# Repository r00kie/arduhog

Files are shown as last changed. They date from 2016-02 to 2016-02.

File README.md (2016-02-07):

# Arduhog #

The aim of this project is to create pcb diagrams and software thanks to it will be possible to build hardware cockpit simulator for DCS A10C (and maybe more). PCB board and software try to simulate HID interface (keyboard exactly), so the knowledge that it is available here should also fit for other simulators/games. 

I'm lazy so im using Arduino Nano as main controller, it's cheap (if you are using chinese replacements), it's popular, you don't need any advanced hardware programmer and when you will be bored with this project you can use it for something else.

Project requires [this library](https://git.io/vgGM2) for working. You have to install it in your Arduino IDE.

You can also check [DCS-Bios](http://dcs-bios.a10c.de/), but it have a different approach, it's requires installing some additional scripts in DCS World and it's works only with A10C Cocpit. 

## Project Structure Description

### Hardware ###

  * eagle/ - directory containing EAGLE project; 
  * eagle/main_board - pcb diagrams for main board; mainly it contains all necessary components to simulate hardware keyboard and other stuff to indicate device status, some buttons (currently they do nothing); main board have 8 expansions port for extension board, it allows you to, theoretically, support up to 64 buttons/switches; connection to the PC is done via the USB B port (why B? because it is the simplest USB port for soldering and it fit to 100 mil boards)
  * eagle/ext_board - pcb diagrams for extension board; thanks to this board you can connect up to 16 button; 
  * eagle/ahcp - only schematic, how to connect switches from Armament Hud Control Panel to port what will fit extension board;
  * eagle/bom/* - Bill of Materials for pcb boards;
  * eagle/tests/* - tests and early material created for this project;

### Software ###

  * src/arduhog/* - source code for arduino controller;
  * src/arduhog/keymappings.ods - spreedsheet containing mapping from eagle/ahcp.sch to buttons in code and shortcuts in game.  

## Screenshots, images and movies  
  
  * [Image gallery of prototype](https://imgur.com/a/71ZCE)
  * [Working prototype](https://vid.me/YhLZ)

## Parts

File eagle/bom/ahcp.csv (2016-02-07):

Qty | Value | Device | Package | Parts | Description | A10
2 |  | PINHD-2X8 | 2X08 | JP1, JP2 | PIN HEADER
1 | MTS-103 | TL39PO | TL3XPO | S5 | TINY SWITCH ON OFF ON | Alt Sce
1 | MTS-103 | TL39PO | TL3XPO | S2 | TINY SWITCH ON OFF ON | GunPac
1 | MTS-103 | TL39PO | TL3XPO | S10 | TINY SWITCH ON OFF ON | IFFCC
1 | MTS-103 | TL39PO | TL3XPO | S3 | TINY SWITCH ON OFF ON | LASER Arm
1 | MTS-103 | TL39PO | TL3XPO | S1 | TINY SWITCH ON OFF ON | Master Arm
1 | MTS102 | TL36PO | TL3XPO | S8 | TINY SWITCH ON - ON | CICU
1 | MTS102 | TL36PO | TL3XPO | S6 | TINY SWITCH ON - ON | HUD Mode 1
1 | MTS102 | TL36PO | TL3XPO | S7 | TINY SWITCH ON - ON | HUD Mode 2
1 | MTS102 | TL36PO | TL3XPO | S9 | TINY SWITCH ON - ON | JTRS
1 | MTS102 | TL36PO | TL3XPO | S4 | TINY SWITCH ON - ON | TGP

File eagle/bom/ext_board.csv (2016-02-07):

Qty | Value | Device | Package | Parts | Description | TME_CODE
1 |  | LED3MM | LED3MM | LED1 | LED | L-934ID
2 |  | PINHD-2X8 | 2X08 | JP1, JP2 | PIN HEADER | 826632-8
1 | 100nF | C-EU050-030X075 | C050-030X075 | C2 | CAPACITOR, European symbol | CC-100N
19 | 10K | R-EU_0204/7 | 0204/7 | R1, R2, R3, R4, R5, R6, R7, R8, R9, R10, R11, R12, R13, R14, R15, R16, R18, R19, R20 | RESISTOR, European symbol | CF1/2WS-10K
1 | 10uF | CPOL-EUE2.5-7 | E2,5-7 | C3 | POLARIZED CAPACITOR, European symbol | UPW2A100MED
1 | 1N4001 | 1N4004 | DO41-10 | D1 | DIODE | 1N4001
1 | 270 | R-EU_0204/7 | 0204/7 | R21 | RESISTOR, European symbol | CF1/2WS-270R
1 | 33pF | C-EU050-030X075 | C050-030X075 | C1 | CAPACITOR, European symbol | FKP2-33P/1000-R
1 | 3K9 | R-EU_0204/7 | 0204/7 | R17 | RESISTOR, European symbol | 1/4W3.9K
1 | A6EX-310X | A6EX-310X | A6EX-310X | S1 | OMRON | A6E-3104
1 | MCP23016-I/SP | DIL28-3 | DIL28-3 | IC1 | Dual In Line | MCP23016-I/SP
1 | MX-171857-0004 | MX-171857-0004 | MX-171857-0004 | X1 |  | MX-7395-04B

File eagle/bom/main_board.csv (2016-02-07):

Qty | Value | Device | Package | Parts | Description | DX_CODE | MF | MPN | OC_FARNELL | OC_NEWARK | TME_CODE
1 | 100nF | C-EU050-030X075 | C050-030X075 | C2 | CAPACITOR, European symbol |  |  |  |  |  | CC-100N
1 | 10uF | CPOL-EUE2.5-7 | E2,5-7 | C3 | POLARIZED CAPACITOR, European symbol |  |  |  |  |  | UPW2A100MED
2 | 1K | R-EU_0204/7 | 0204/7 | R1, R2 | RESISTOR, European symbol |  |  |  |  |  | CF1/4W-1K
3 | 270 | R-EU_0204/7 | 0204/7 | R7, R8, R9 | RESISTOR, European symbol |  |  |  |  |  | CF1/2WS-270R
1 | 2K2 | R-EU_0204/7 | 0204/7 | R10 | RESISTOR, European symbol |  |  |  |  |  | 1/4W2.2K
2 | 3V6 | ZPD | DO35Z10 | D1, D2 | Z DIODE |  |  |  |  |  | ZPD3.6-DIO
2 | 68 | R-EU_0204/7 | 0204/7 | R11, R12 | RESISTOR, European symbol |  |  |  |  |  | CF1/2WS-68R
1 | Arduino Nano | DIL32 | DIL32 | IC1 | Dual In Line | 844081877 |  |  |  |  | N/A
2 | B3F-1000 | 10-XX | B3F-10XX | S1, S2 | OMRON SWITCH |  |  | B3F-1000 | 176432 | 36M3542 | B3F-1002
1 | GREEN | TLLR4400 | LED3MM | LED2 | Low Current (2mA) LED 3 mm Tinted Diffused Package color RED |  | VISHAY SEMICONDUCTOR |  | 1612437 |  | L-934GD
1 | MINI-USB_4P-85-32004-10X | MINI-USB_4P-85-32004-10X | 85-32004-10X | X9 | MINI USB 4 Pol. |  |  |  | unknown | unknown | USBB-G
8 | MX-171857-0004 | MX-171857-0004 | MX-171857-0004 | X1, X2, X3, X4, X5, X6, X7, X8 |  |  |  |  |  |  | MX-7395-04B
1 | RED | TLLR4400 | LED3MM | LED1 | Low Current (2mA) LED 3 mm Tinted Diffused Package color RED |  | VISHAY SEMICONDUCTOR |  | 1612437 |  | L-934ID
1 | YELLOW | TLLR4400 | LED3MM | LED3 | Low Current (2mA) LED 3 mm Tinted Diffused Package color RED |  | VISHAY SEMICONDUCTOR |  | 1612437 |  | L-934YD

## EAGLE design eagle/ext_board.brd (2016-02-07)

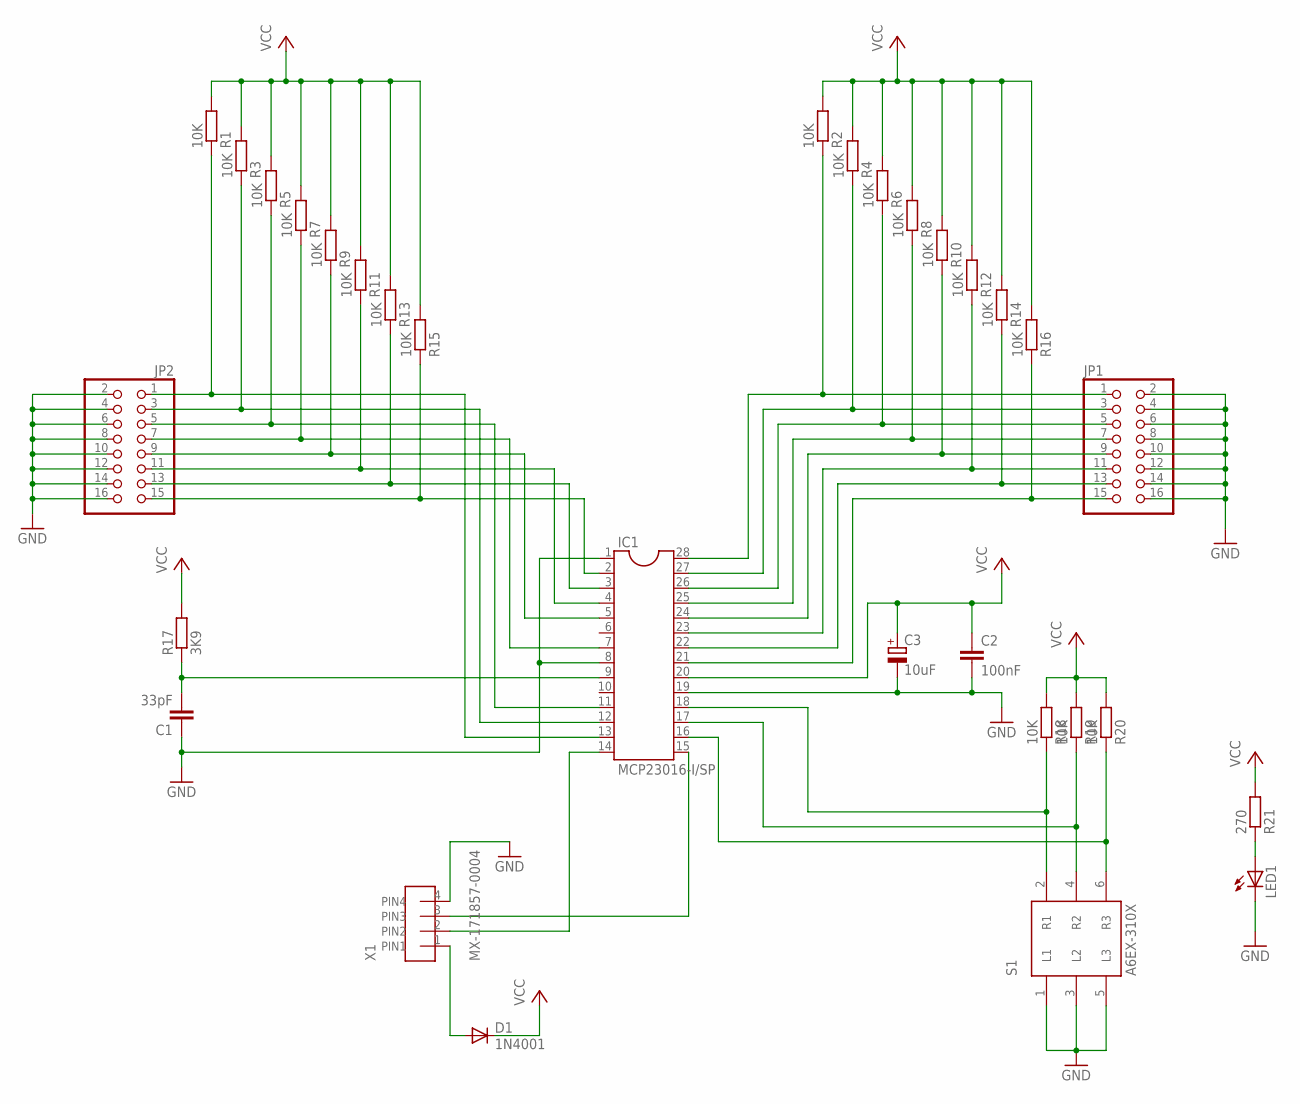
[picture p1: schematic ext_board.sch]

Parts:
C1: 33pF; C050-030X075
C2: 100nF; C050-030X075
C3: 10uF; E2,5-7
D1: 1N4001; DO41-10
IC1: MCP23016-I/SP; DIL28-3
JP1, JP2: PINHD-2X8; 2X08
LED1: LED3MM
R1, R2, R3, R4, R5, R6, R7, R8, R9, R10, R11, R12, R13, R14, R15, R16, R18, R19, R20: 10K; 0204/7
R17: 3K9; 0204/7
R21: 270; 0204/7
S1: A6EX-310X
X1: MX-171857-0004

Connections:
GND: C1.1, C2.2, C3.-, IC1.1, IC1.8, IC1.19, JP1.2, JP1.4, JP1.6, JP1.8, JP1.10, JP1.12, JP1.14, JP1.16, JP2.2, JP2.4, JP2.6, JP2.8, JP2.10, JP2.12, JP2.14, JP2.16, LED1.K (C), S1.1 (L1), S1.3 (L2), S1.5 (L3), X1.4 (PIN4)
GP0.0: IC1.21, JP1.15, R16.1
GP0.1: IC1.22, JP1.13, R14.1
GP0.2: IC1.23, JP1.11, R12.1
GP0.3: IC1.2, JP2.15, R15.1
GP0.4: IC1.3, JP2.13, R13.1
GP0.5: IC1.4, JP2.11, R11.1
unnamed: C1.2, IC1.9, R17.1
unnamed: IC1.18, R18.1, S1.2 (R1)
unnamed: IC1.17, R19.1, S1.4 (R2)
unnamed: IC1.5, JP2.9, R9.1
unnamed: IC1.7, JP2.7, R7.1
unnamed: D1.A, X1.1 (PIN1)
unnamed: IC1.11, JP2.5, R5.1
unnamed: IC1.16, R20.1, S1.6 (R3)
unnamed: IC1.24, JP1.9, R10.1
unnamed: IC1.25, JP1.7, R8.1
unnamed: IC1.26, JP1.5, R6.1
unnamed: IC1.27, JP1.3, R4.1
unnamed: IC1.28, JP1.1, R2.1
unnamed: IC1.12, JP2.3, R3.1
unnamed: IC1.13, JP2.1, R1.1
unnamed: LED1.A, R21.1
SCL: IC1.14, X1.2 (PIN2)
SDA: IC1.15, X1.3 (PIN3)
VCC: C2.1, C3.+, D1.C, IC1.20, R1.2, R2.2, R3.2, R4.2, R5.2, R6.2, R7.2, R8.2, R9.2, R10.2, R11.2, R12.2, R13.2, R14.2, R15.2, R16.2, R17.2, R18.2, R19.2, R20.2, R21.2

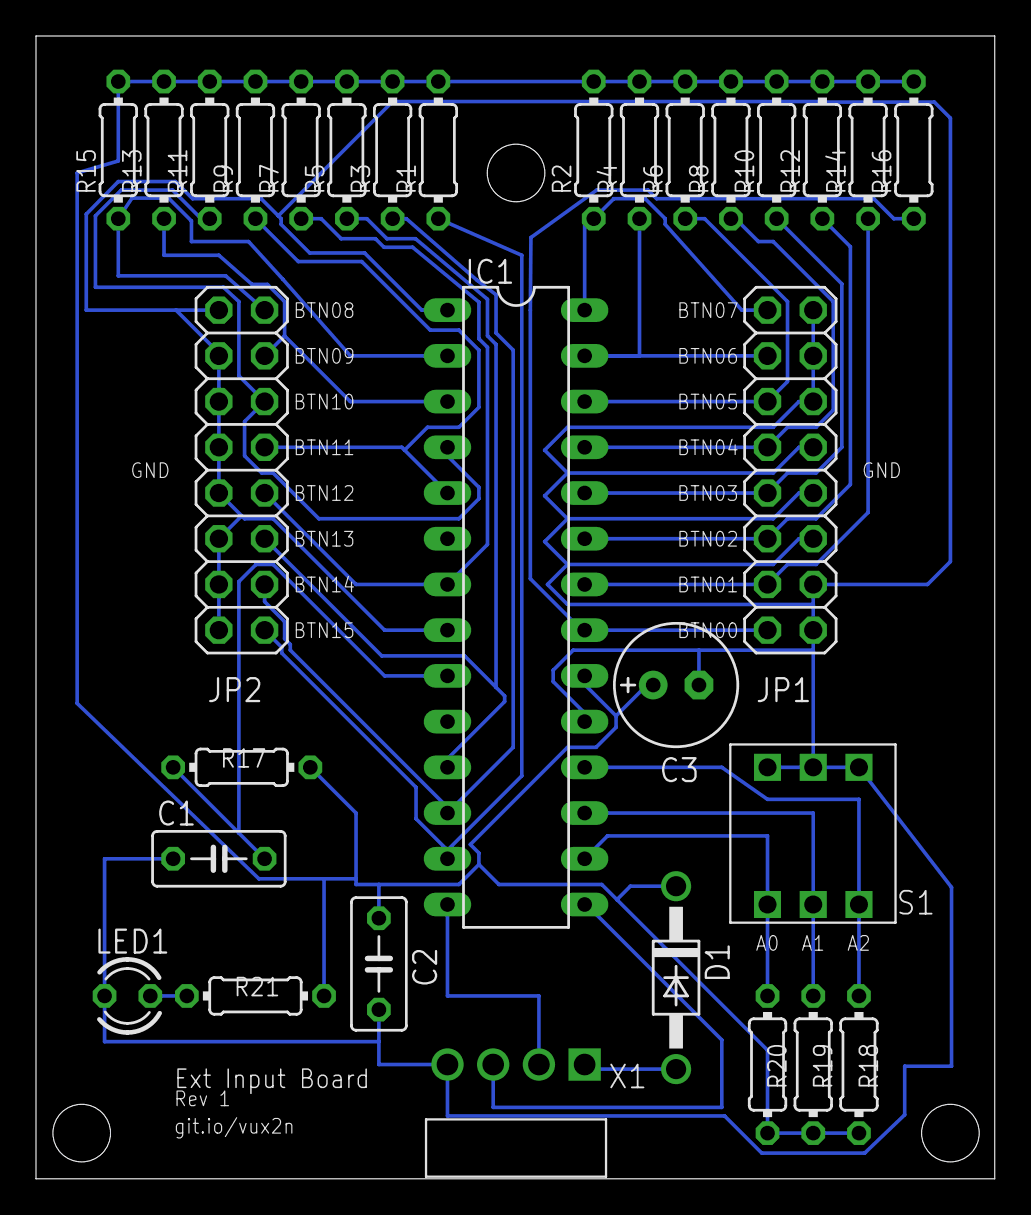
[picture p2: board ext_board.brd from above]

Board: 2 copper layers, 53.3 x 63.5 mm, 31 parts (0 on the bottom side), 26 nets.

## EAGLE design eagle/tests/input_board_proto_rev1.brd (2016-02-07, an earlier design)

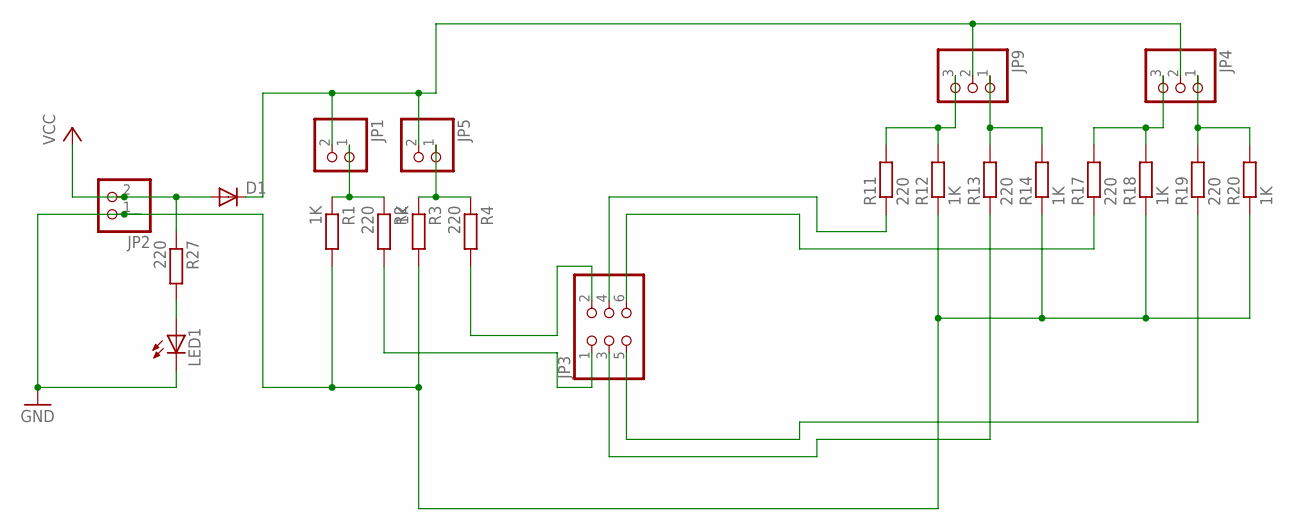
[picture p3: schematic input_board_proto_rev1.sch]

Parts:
D1: DIODE-C1702-05; C1702-05
JP1, JP2, JP5: PINHD-1X2; 1X02
JP3: PINHD-2X3; 2X03
JP4, JP9: PINHD-1X3; 1X03
LED1: LED3MM
R1, R3, R12, R14, R18, R20: 1K; 0204V
R2, R4, R11, R13, R17, R19, R27: 220; 0204V

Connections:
GND: JP2.1, LED1.K (C), R1.2, R3.2, R12.1, R14.1, R18.1, R20.1
unnamed: JP1.1, R1.1, R2.1
unnamed: JP5.1, R3.1, R4.1
unnamed: JP3.1, R2.2
unnamed: JP3.2, R4.2
unnamed: JP9.3, R11.2, R12.2
unnamed: JP9.1, R13.2, R14.2
unnamed: JP4.3, R17.2, R18.2
unnamed: JP4.1, R19.2, R20.2
unnamed: JP3.6, R17.1
unnamed: JP3.4, R11.1
unnamed: JP3.5, R19.1
unnamed: JP3.3, R13.1
unnamed: LED1.A, R27.2
unnamed: D1.C, JP1.2, JP4.2, JP5.2, JP9.2
VCC: D1.A, JP2.2, R27.1

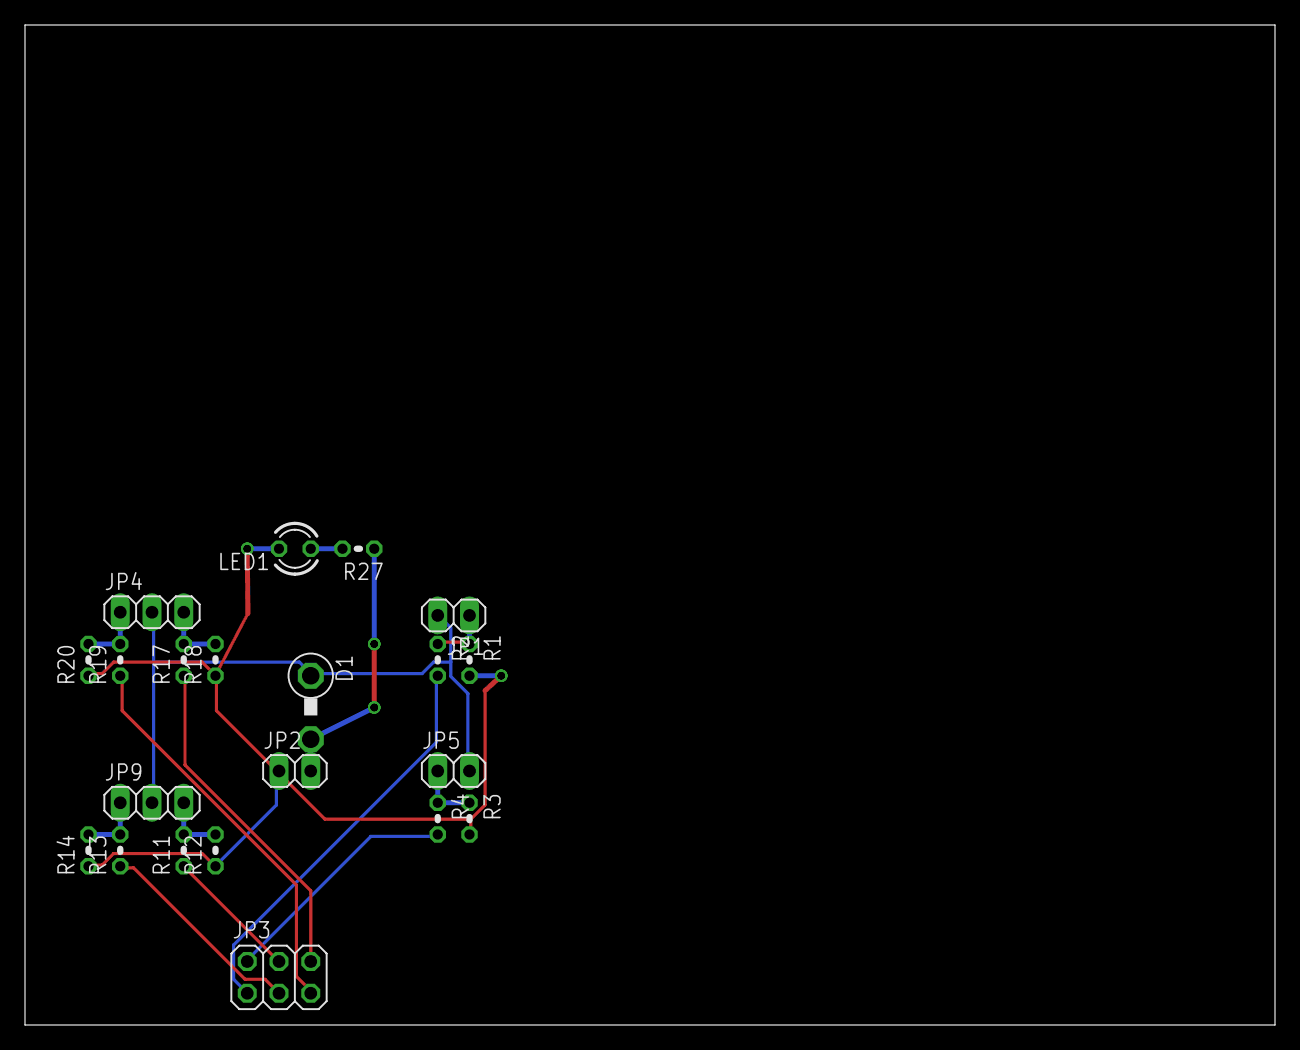
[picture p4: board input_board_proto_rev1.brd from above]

Board: 2 copper layers, 100.0 x 80.0 mm, 21 parts (0 on the bottom side), 16 nets.

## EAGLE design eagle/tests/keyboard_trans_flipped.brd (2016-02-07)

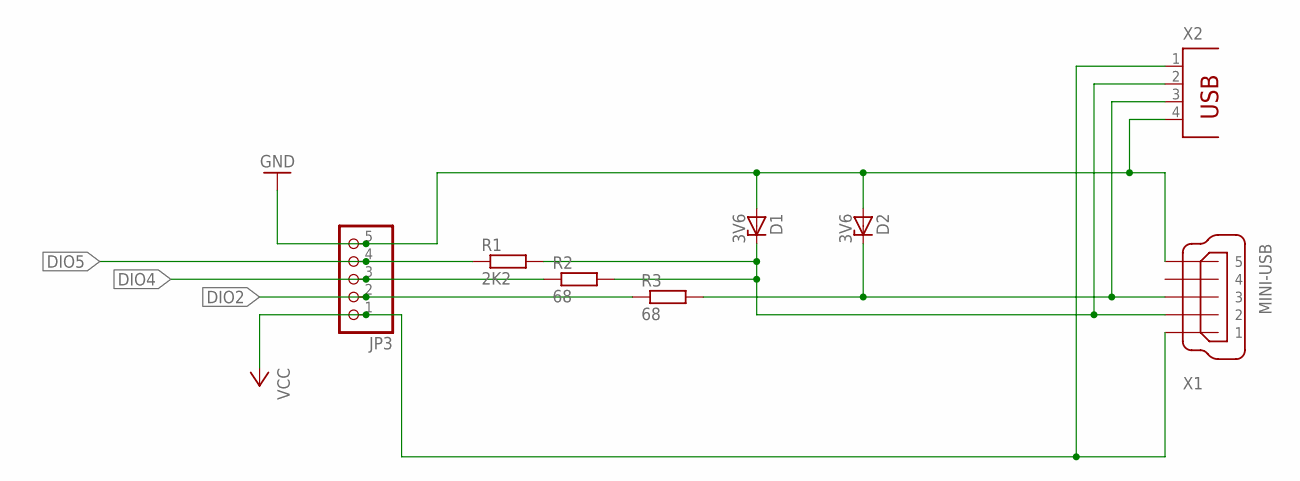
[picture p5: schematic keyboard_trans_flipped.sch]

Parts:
D1, D2: 3V6; DO35Z10
JP3: PINHD-1X5; 1X05
R1: 2K2; 0204/5
R2, R3: 68; 0204/5
X1: MINI-USB; UX60-MB-5S8
X2: PN61729

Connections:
DIO2: JP3.2, R3.1
DIO4: JP3.3, R2.1
DIO5: JP3.4, R1.1
GND: D1.A, D2.A, JP3.5, X1.5, X2.4
unnamed: D1.C, R1.2, R2.2, X1.2, X2.2
unnamed: D2.C, R3.2, X1.3, X2.3
VCC: JP3.1, X1.1, X2.1

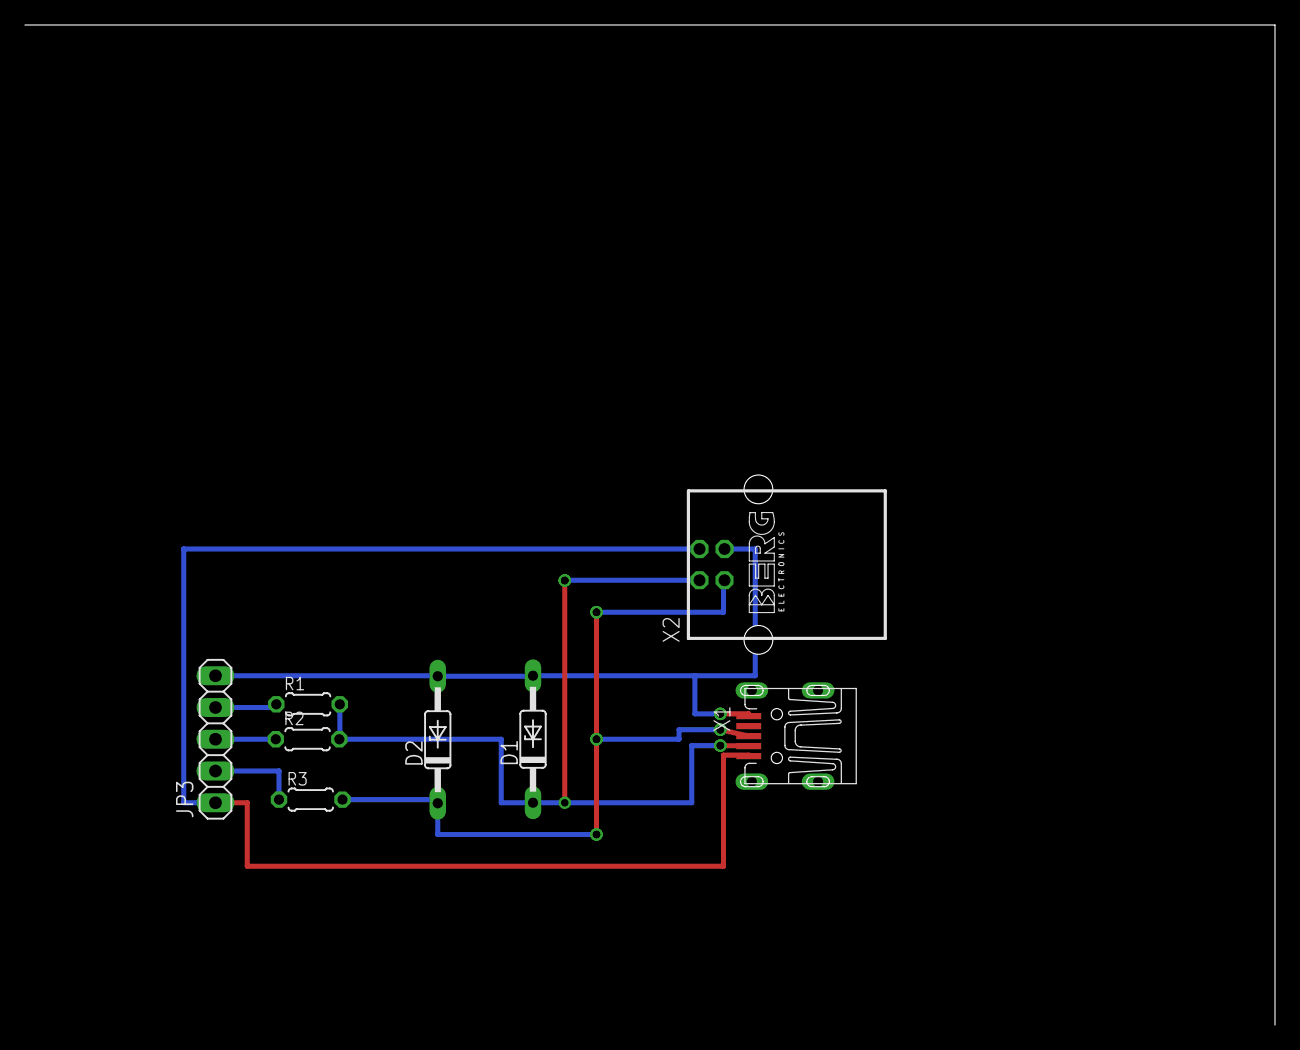
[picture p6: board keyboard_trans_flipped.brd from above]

Board: 2 copper layers, 100.0 x 80.0 mm, 8 parts (0 on the bottom side), 7 nets.

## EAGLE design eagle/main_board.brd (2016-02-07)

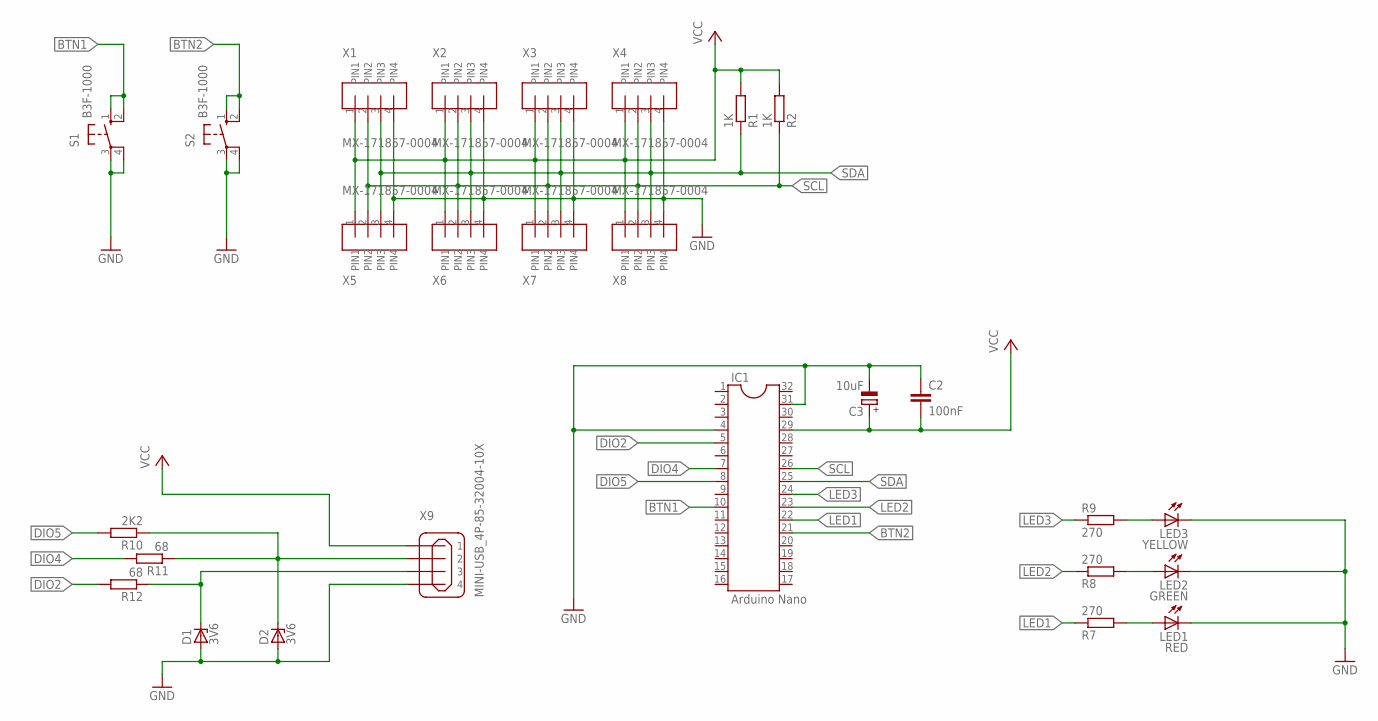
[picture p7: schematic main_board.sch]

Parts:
C2: 100nF; C050-030X075
C3: 10uF; E2,5-7
D1, D2: 3V6; DO35Z10
IC1: Arduino Nano; DIL32
LED1: RED; LED3MM
LED2: GREEN; LED3MM
LED3: YELLOW; LED3MM
R1, R2: 1K; 0204/7
R7, R8, R9: 270; 0204/7
R10: 2K2; 0204/7
R11, R12: 68; 0204/7
S1, S2: B3F-1000; B3F-10XX
X1, X2, X3, X4, X5, X6, X7, X8: MX-171857-0004
X9: MINI-USB_4P-85-32004-10X; 85-32004-10X

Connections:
BTN1: IC1.10, S1.1 (S), S1.2 (S1)
BTN2: IC1.21, S2.1 (S), S2.2 (S1)
DIO2: IC1.5, R12.2
DIO4: IC1.7, R11.2
DIO5: IC1.8, R10.2
GND: C2.1, C3.-, D1.A, D2.A, IC1.4, IC1.31, LED1.K (C), LED2.K (C), LED3.K (C), S1.3, S1.4 (P1), S2.3, S2.4 (P1), X1.4 (PIN4), X2.4 (PIN4), X3.4 (PIN4), X4.4 (PIN4), X5.4 (PIN4), X6.4 (PIN4), X7.4 (PIN4), X8.4 (PIN4), X9.4
LED1: IC1.22, R7.1
LED2: IC1.23, R8.1
LED3: IC1.24, R9.1
unnamed: LED3.A, R9.2
unnamed: D1.C, R12.1, X9.3
unnamed: D2.C, R10.1, R11.1, X9.2
unnamed: LED2.A, R8.2
unnamed: LED1.A, R7.2
SCL: IC1.26, R2.1, X1.2 (PIN2), X2.2 (PIN2), X3.2 (PIN2), X4.2 (PIN2), X5.2 (PIN2), X6.2 (PIN2), X7.2 (PIN2), X8.2 (PIN2)
SDA: IC1.25, R1.1, X1.3 (PIN3), X2.3 (PIN3), X3.3 (PIN3), X4.3 (PIN3), X5.3 (PIN3), X6.3 (PIN3), X7.3 (PIN3), X8.3 (PIN3)
VCC: C2.2, C3.+, IC1.29, R1.2, R2.2, X1.1 (PIN1), X2.1 (PIN1), X3.1 (PIN1), X4.1 (PIN1), X5.1 (PIN1), X6.1 (PIN1), X7.1 (PIN1), X8.1 (PIN1), X9.1

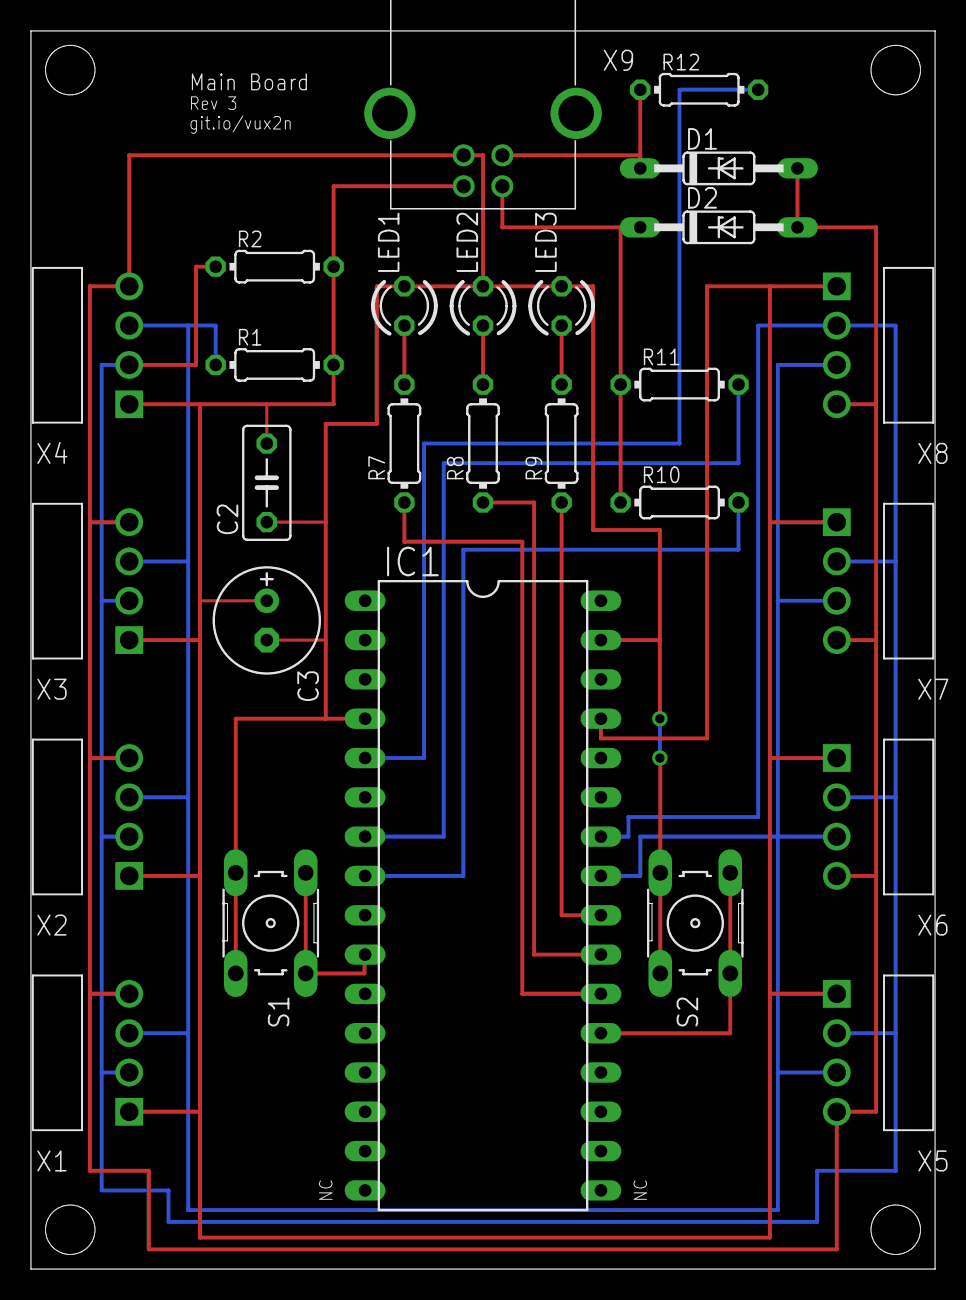
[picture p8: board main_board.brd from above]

Board: 2 copper layers, 58.4 x 80.0 mm, 27 parts (0 on the bottom side), 17 nets.

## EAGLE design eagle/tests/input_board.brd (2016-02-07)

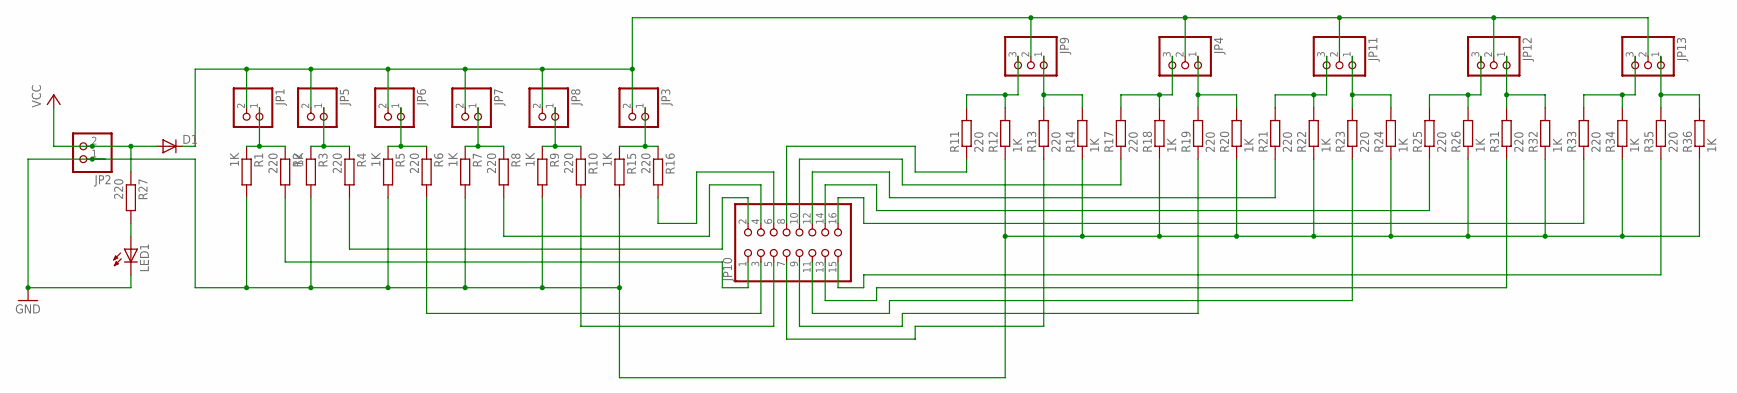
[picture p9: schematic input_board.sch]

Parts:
D1: DIODE-C1702-05; C1702-05
JP1, JP2, JP3, JP5, JP6, JP7, JP8: PINHD-1X2; 1X02
JP4, JP9, JP11, JP12, JP13: PINHD-1X3; 1X03
JP10: PINHD-2X8; 2X08
LED1: LED3MM
R1, R3, R5, R7, R9, R12, R14, R15, R18, R20, R22, R24, R26, R32, R34, R36: 1K; 0204V
R2, R4, R6, R8, R10, R11, R13, R16, R17, R19, R21, R23, R25, R27, R31, R33, R35: 220; 0204V

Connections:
GND: JP2.1, LED1.K (C), R1.2, R3.2, R5.2, R7.2, R9.2, R12.1, R14.1, R15.2, R18.1, R20.1, R22.1, R24.1, R26.1, R32.1, R34.1, R36.1
unnamed: JP1.1, R1.1, R2.1
unnamed: JP3.1, R15.1, R16.1
unnamed: JP10.16, R33.1
unnamed: JP5.1, R3.1, R4.1
unnamed: JP6.1, R5.1, R6.1
unnamed: JP7.1, R7.1, R8.1
unnamed: JP8.1, R9.1, R10.1
unnamed: JP10.1, R2.2
unnamed: JP10.2, R4.2
unnamed: JP10.3, R6.2
unnamed: JP10.4, R8.2
unnamed: JP10.5, R10.2
unnamed: JP10.6, R16.2
unnamed: JP9.3, R11.2, R12.2
unnamed: JP9.1, R13.2, R14.2
unnamed: JP10.14, R25.1
unnamed: JP4.3, R17.2, R18.2
unnamed: JP4.1, R19.2, R20.2
unnamed: JP11.3, R21.2, R22.2
unnamed: JP11.1, R23.2, R24.2
unnamed: JP12.3, R25.2, R26.2
unnamed: JP12.1, R31.2, R32.2
unnamed: JP13.3, R33.2, R34.2
unnamed: JP13.1, R35.2, R36.2
unnamed: JP10.12, R21.1
unnamed: JP10.10, R17.1
unnamed: JP10.8, R11.1
unnamed: JP10.15, R35.1
unnamed: JP10.13, R31.1
unnamed: JP10.11, R23.1
unnamed: JP10.9, R19.1
unnamed: JP10.7, R13.1
unnamed: LED1.A, R27.2
unnamed: D1.C, JP1.2, JP3.2, JP4.2, JP5.2, JP6.2, JP7.2, JP8.2, JP9.2, JP11.2, JP12.2, JP13.2
VCC: D1.A, JP2.2, R27.1

Board: 2 copper layers, 48 parts (0 on the bottom side), 36 nets, no tracks yet.

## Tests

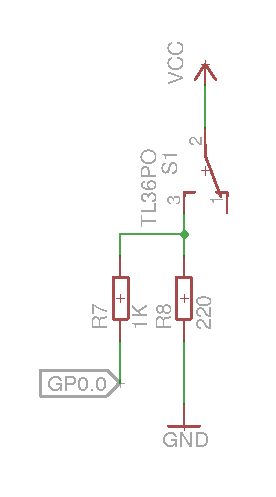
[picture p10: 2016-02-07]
eagle/tests/2_way_switch.png

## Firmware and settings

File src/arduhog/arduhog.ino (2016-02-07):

#include "UsbKeyboard.h"
#include "IoExtender.h"
#include "EventFunctions.h"

#define LAZY_INIT_DELAY 1000
#define SEND_KEYS 1

#define STATUS_LED_PIN 15
#define GREEN_LED_PIN 16
#define YELLOW_LED_PIN 17

#define BUTTON_1_PIN 2
#define BUTTON_2_PIN 3

#define KEY_SCROLL_LOCK 71


char hello_pressed[] = { KEY_H, KEY_E, KEY_L, KEY_L, KEY_O, KEY_SPACE, 0x00 };
char world_released[] = { KEY_W, KEY_O, KEY_R, KEY_L, KEY_D, 0x00 };

IoExtender *dyn_all_extenders[] = {NULL, NULL, NULL, NULL, NULL, NULL, NULL};

bool lazy_setup_initialized = 0;
uint16_t last_btn_update_time = 0;

void setup() {     
  Serial.begin(9600);     

  UsbKeyboard.update();
  pinMode(STATUS_LED_PIN, OUTPUT);
  pinMode(GREEN_LED_PIN, OUTPUT);
  pinMode(YELLOW_LED_PIN, OUTPUT);

  digitalWrite(STATUS_LED_PIN, HIGH);
  digitalWrite(GREEN_LED_PIN, HIGH);
  digitalWrite(YELLOW_LED_PIN, HIGH);
}

uint8_t delayed_setup() {
  uint8_t setup_status = 0;
  uint8_t io_extender_status = -1;
  uint8_t io_extender_status_global = -1;
  IoExtender *extender;
  
  Serial.println("--------------------");
  Serial.println("     Lazy init      ");
  Serial.println("--------------------");


  // initializing multiplexers 
  for (uint8_t ext_number = 0; ext_number < IO_EXTENDER_NUMBER; ext_number++) {
    extender = new IoExtender();
    io_extender_status = extender->init(IO_EXTENDER_START_ADDRESS + ext_number);      
    
    if (io_extender_status == 0) {      
      // multiplexer found - so we need to initialize it
      Serial.println("FOUND");
      
      extender->invertPortsPolarity();
      extender->getPortsStatus();  

      dyn_all_extenders[ext_number] = extender;
      
      io_extender_status_global = 0;      
    } else {
      // multiplexer not found - we null it so it wont bother as later            
      Serial.println("NOT FOUND");
      
      delete extender;
    }    
  }
  
  if (io_extender_status_global == 0) {
    // at least one multiplexer found    
    digitalWrite(YELLOW_LED_PIN, LOW);
  } else {
    setup_status++;
  }

  // checking keyboard connection
  UsbKeyboard.sendKeyStroke(KEY_SCROLL_LOCK);
  UsbKeyboard.sendKeyStroke(KEY_SCROLL_LOCK);
  
  digitalWrite(GREEN_LED_PIN, LOW);

  return setup_status;
}

void handle_buttons() {
  uint8_t btn_num;
  int8_t changes[IO_EXTENDER_PORT_NUMBER];

  for (uint8_t io_number=0;io_number<IO_EXTENDER_NUMBER;io_number++) {
    if (dyn_all_extenders[io_number] != NULL) {
      
      dyn_all_extenders[io_number]->getChanges(changes);
      for (btn_num=0;btn_num<IO_EXTENDER_PORT_NUMBER;btn_num++) {
        if (changes[btn_num] != 0) {

          Serial.print("IO");
          Serial.print(io_number);          
          Serial.print("BTN");
          Serial.print(btn_num);
          
          if (changes[btn_num] > 0) {
            Serial.println("_PRESSED");  
            if (SEND_KEYS) {  
              (*pressed_event[(IO_EXTENDER_PORT_NUMBER*io_number)+btn_num])();
            }
          } else {
            Serial.println("_RELEASED");
            if (SEND_KEYS) {
              (*released_event[(IO_EXTENDER_PORT_NUMBER*io_number)+btn_num])();
            }
          }      
        } 
      }       
    }
  }      
}

void loop() {  
  UsbKeyboard.update();
  
  if (lazy_setup_initialized == 0) {
    pre_init_loop();
  } else {
    after_init_loop();
  }
  
  delay(10);
}

void pre_init_loop() {
  uint16_t current_time = millis(); 

  if ((current_time / 100) % 2 == 0) {
    digitalWrite(STATUS_LED_PIN, HIGH);
  } else {
    digitalWrite(STATUS_LED_PIN, LOW);
  }
  
  if (current_time > LAZY_INIT_DELAY) {
    uint8_t delayed_status = delayed_setup();    
    if (delayed_status == 0) {
      lazy_setup_initialized = 1;       
    }
  }  
}

void after_init_loop() {
  uint16_t current_time = millis(); 

  if ((current_time / 100) % 50 == 0) {
    digitalWrite(STATUS_LED_PIN, LOW);
  } else {
    digitalWrite(STATUS_LED_PIN, HIGH);
  }

  if (current_time - last_btn_update_time > 100) {
    handle_buttons();  
    last_btn_update_time = current_time;
  }  
}


void sendKeyboardInput(char input[]) {
  int c;
  int i=0;
  int limit = 100; // dla bezpieczeństwa :s

  Serial.println("Sending USB: ");
  do {
    limit-=1;
    c = input[i++];
    if (c != 0x00) {
      Serial.print(c);
      Serial.print(":");
      UsbKeyboard.sendKeyStroke((byte)c);
    }
    
  } while (c != 0x00 && limit > 0);

  Serial.println("\nEND USB");
}

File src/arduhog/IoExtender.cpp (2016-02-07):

#include "Arduino.h"
#include "IoExtender.h"
#include "Wire.h"

boolean IoExtender::_wire_init = 0;

IoExtender::IoExtender() {
  _init = 0;  
  _portsStatus = 0;
}

uint8_t IoExtender::init(uint8_t address) {
  _address = address; 
  _init = 1;
  uint8_t result = 0;

  Serial.print("IoExtender(");
  Serial.print(_address);
  Serial.println(")");  

  if (_wire_init == 0) {
    Wire.begin();
    _wire_init = 1;  
  }

  Wire.beginTransmission(_address);
  Wire.write(0x06);  // iodir0 
  Wire.write(0xFF);  // DDR Port0 all input    
  result = Wire.endTransmission(); 

  if (result == 0) {  
    Wire.beginTransmission(_address);
    Wire.write(0x07);  // iodir1 
    Wire.write(0xFF);  // DDR Port1 all input    
    result = Wire.endTransmission();  
  }
  
  return result;
}

void IoExtender::invertPortsPolarity() {
  Wire.beginTransmission(_address);
  Wire.write(0x04);  // ipol0 
  Wire.write(0xFF);  // DDR Port0 invert all ports   
  Wire.endTransmission(); 

  
  Wire.beginTransmission(_address);
  Wire.write(0x05);  // ipol1 
  Wire.write(0xFF);  // DDR Port1 invert all ports   
  Wire.endTransmission();   
}

uint16_t IoExtender::getCurrentPortStatus() {
  uint8_t port0 = 0;
  uint8_t port1 = 0;
  uint16_t result = 0;
  
  Wire.beginTransmission(_address);
  Wire.write(0x00);
  Wire.endTransmission();   

  Wire.requestFrom(_address, (uint8_t)1);
  port0 = Wire.read();

  Wire.beginTransmission(_address);
  Wire.write(0x01);
  Wire.endTransmission();  

  Wire.requestFrom(_address, (uint8_t)1);
  port1 = Wire.read();

  result |= port1;
  result = result << 8;
  result |= port0;

  return result;   
}

uint16_t IoExtender::getPortsStatus() {    
  _portsStatus = getCurrentPortStatus();
  
  return _portsStatus;  
}

void IoExtender::getChanges(int8_t changes[]) {
  uint16_t index = 0;
  uint16_t mask = 0;
  int16_t actual = 0;
  int16_t prev = 0;
  
  uint16_t current = getCurrentPortStatus();  

  for (index=0;index<IO_EXTENDER_PORT_NUMBER;index++) {
    actual = 0;
    prev = 0;
    mask = 1 << index;    

    actual = (current & mask) / mask;
    prev = (_portsStatus & mask) / mask;   

    changes[index] = actual - prev;    
  } 
  
  _portsStatus = current;
  
}
